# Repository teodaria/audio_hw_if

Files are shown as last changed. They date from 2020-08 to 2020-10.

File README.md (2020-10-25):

# hw_dev

This board is designed around AD1983 codec as an expansion board for the STM32MP157C-DK2 evaluation board.
It adds the capability to connect musical intruments to the STM32MP1 and output the processed audio with low latency.

Main features:
 * [AD1983](https://www.analog.com/en/products/ad1983.html) 4 in / 8 out codec
 * [LDLN030](https://www.st.com/en/power-management/ldln030.html) ultra-low noise LDO to generate a clean analog power for the codec and the analog circuitry
 * [TS922](https://www.st.com/content/st_com/en/products/amplifiers-and-comparators/operational-amplifiers-op-amps/automotive-op-amps/ts922.html) low noise audio operational amplifiers
 * 2 input connectors
 * 2 output connectors
 * headphones connector

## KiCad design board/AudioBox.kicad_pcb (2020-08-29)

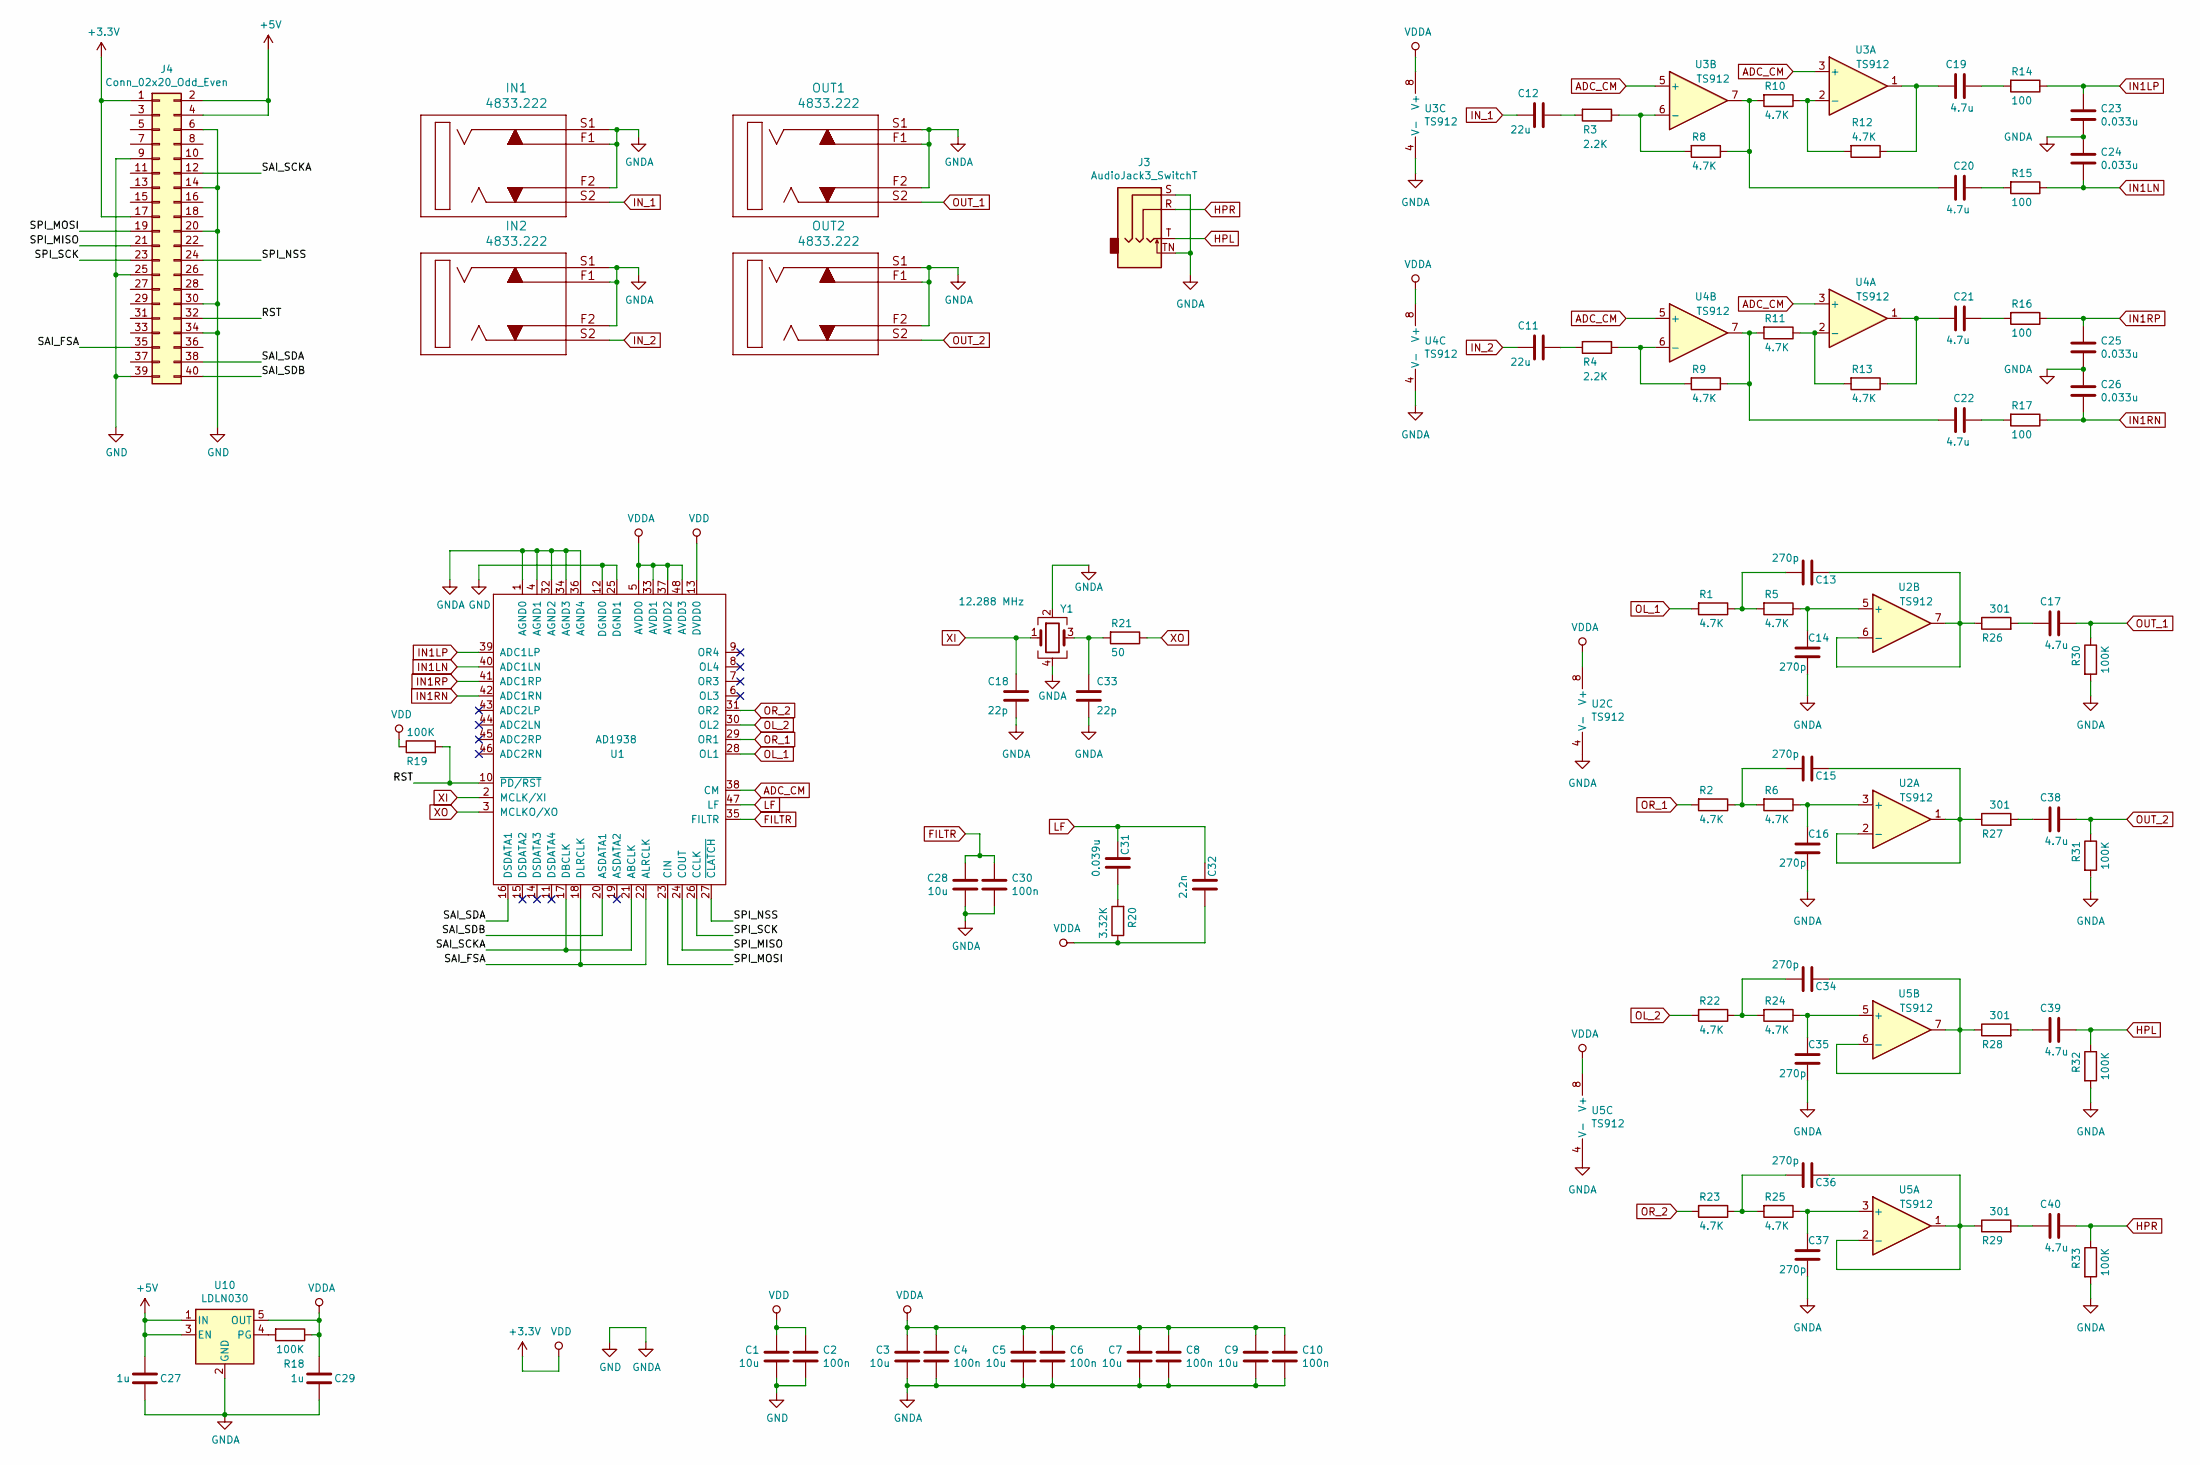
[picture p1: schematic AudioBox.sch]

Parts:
C1, C3, C5, C7, C9, C28: 10u; C_0603_1608Metric_Pad1.05x0.95mm_HandSolder; Voltage 25V; Tolerance 10%
C2, C4, C6, C8, C10, C30: 100n; C_0603_1608Metric_Pad1.05x0.95mm_HandSolder; Voltage 25V; Tolerance 10%
C11, C12: 22u; C_0603_1608Metric_Pad1.05x0.95mm_HandSolder; Voltage 10V; Tolerance 20%
C13, C14, C15, C16, C34, C35, C36, C37: 270p; C_0603_1608Metric_Pad1.05x0.95mm_HandSolder; Voltage 100V; Tolerance 1%
C17, C19, C20, C21, C22, C38, C39, C40: 4.7u; C_0603_1608Metric_Pad1.05x0.95mm_HandSolder; Voltage 16V; Tolerance 10%
C18, C33: 22p; C_0603_1608Metric_Pad1.05x0.95mm_HandSolder; Voltage 16V; Tolerance 5%
C23, C24, C25, C26: 0.033u; C_0603_1608Metric_Pad1.05x0.95mm_HandSolder; Voltage 16V; Tolerance 10%
C27, C29: 1u; C_0603_1608Metric_Pad1.05x0.95mm_HandSolder; Voltage 16V; Tolerance 10%
C31: 0.039u; C_0603_1608Metric_Pad1.05x0.95mm_HandSolder; Voltage 50V; Tolerance 10%
C32: 2.2n; C_0603_1608Metric_Pad1.05x0.95mm_HandSolder; Voltage 50V; Tolerance 10%
IN1, IN2: 4833.222
J3: AudioJack3_SwitchT; Jack_3.5mm_CUI_SJ-3524-SMT_Horizontal
J4: Conn_02x20_Odd_Even; PinSocket_2x20_P2.54mm_Vertical
OUT1, OUT2: 4833.222
R1, R2, R5, R6, R8, R9, R10, R11, R12, R13, R22, R23, R24, R25: 4.7K; R_0603_1608Metric_Pad1.05x0.95mm_HandSolder; Tolerance 1%
R3, R4: 2.2K; R_0603_1608Metric_Pad1.05x0.95mm_HandSolder; Tolerance 1%
R14, R15, R16, R17: 100; R_0603_1608Metric_Pad1.05x0.95mm_HandSolder; Tolerance 1%
R18, R19, R30, R31, R32, R33: 100K; R_0603_1608Metric_Pad1.05x0.95mm_HandSolder; Tolerance 5%
R20: 3.32K; R_0603_1608Metric_Pad1.05x0.95mm_HandSolder; Tolerance 1%
R21: 50; R_0603_1608Metric_Pad1.05x0.95mm_HandSolder; Tolerance 1%
R26, R27, R28, R29: 301; R_0603_1608Metric_Pad1.05x0.95mm_HandSolder; Tolerance 1%
U1: AD1938; LQFP-48_7x7mm_P0.5mm
U2, U3, U4, U5: TS912; SO-8_5.3x6.2mm_P1.27mm
U10: LDLN030; SOT-23-5
Y1: 12.288 MHz; Crystal_SMD_Abracon_ABM3B-4Pin_5.0x3.2mm

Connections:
+3V3: C1.2, C2.2, J4.1, J4.17, R19.1, U1.13 (DVDD0)
+5V: C27.2, J4.2, J4.4, U10.1 (IN), U10.3 (EN)
/RST: J4.32, R19.2, U1.10 (~PD/RST)
/SAI_FSA: J4.35, U1.18 (DLRCLK), U1.22 (ALRCLK)
/SAI_SCKA: J4.12, U1.17 (DBCLK), U1.21 (ABCLK)
/SAI_SDA: J4.38, U1.16 (DSDATA1)
/SAI_SDB: J4.40, U1.20 (ASDATA1)
/SPI_MISO: J4.21, U1.24 (COUT)
/SPI_MOSI: J4.19, U1.23 (CIN)
/SPI_NSS: J4.24, U1.27 (~CLATCH)
/SPI_SCK: J4.23, U1.26 (CCLK)
ADC_CM: U1.38 (CM), U3.3 (+), U3.5 (+), U4.3 (+), U4.5 (+)
FILTR: C28.2, C30.2, U1.35 (FILTR)
GND: C1.1, C2.1, C3.1, C4.1, C5.1, C6.1, C7.1, C8.1, C9.1, C10.1, C14.2, C16.2, C18.1, C23.1, C24.2, C25.1, C26.2, C27.1, C28.1, C29.1, C30.1, C33.1, C35.2, C37.2, IN1.F1, IN1.F2, IN1.S1, IN2.F1, IN2.F2, IN2.S1, J3.S, J3.TN, J4.6, J4.9, J4.14, J4.20, J4.25, J4.30, J4.34, J4.39, OUT1.F1, OUT1.F2, OUT1.S1, OUT2.F1, OUT2.F2, OUT2.S1, R30.2, R31.2, R32.2, R33.2, U1.1 (AGND0), U1.4 (AGND1), U1.12 (DGND0), U1.25 (DGND1), U1.32 (AGND2), U1.34 (AGND3), U1.36 (AGND4), U2.4 (V-), U3.4 (V-), U4.4 (V-), U5.4 (V-), U10.2 (GND), Y1.2, Y1.4
HPL: C39.1, J3.T, R32.1
HPR: C40.1, J3.R, R33.1
IN1LN: C24.1, R15.1, U1.40 (ADC1LN)
IN1LP: C23.2, R14.1, U1.39 (ADC1LP)
IN1RN: C26.1, R17.1, U1.42 (ADC1RN)
IN1RP: C25.2, R16.1, U1.41 (ADC1RP)
IN_1: C12.2, IN1.S2
IN_2: C11.2, IN2.S2
LF: C31.1, C32.1, U1.47 (LF)
unnamed: C11.1, R4.2
unnamed: C12.1, R3.2
unnamed: C13.1, R26.1, U2.6 (-), U2.7
unnamed: C13.2, R1.1, R5.2
unnamed: C14.1, R5.1, U2.5 (+)
unnamed: C15.1, R27.1, U2.1, U2.2 (-)
unnamed: C15.2, R2.1, R6.2
unnamed: C16.1, R6.1, U2.3 (+)
unnamed: C17.2, R26.2
unnamed: C19.1, R14.2
unnamed: C19.2, R12.1, U3.1
unnamed: C20.1, R8.1, R10.2, U3.7
unnamed: C20.2, R15.2
unnamed: C21.1, R13.1, U4.1
unnamed: C21.2, R16.2
unnamed: C22.1, R9.1, R11.2, U4.7
unnamed: C22.2, R17.2
unnamed: C31.2, R20.2
unnamed: C33.2, R21.2, Y1.3
unnamed: C34.1, R28.1, U5.6 (-), U5.7
unnamed: C34.2, R22.1, R24.2
unnamed: C35.1, R24.1, U5.5 (+)
unnamed: C36.1, R29.1, U5.1, U5.2 (-)
unnamed: C36.2, R23.1, R25.2
unnamed: C37.1, R25.1, U5.3 (+)
unnamed: C38.2, R27.2
unnamed: C39.2, R28.2
unnamed: C40.2, R29.2
unnamed: R3.1, R8.2, U3.6 (-)
unnamed: R4.1, R9.2, U4.6 (-)
unnamed: R10.1, R12.2, U3.2 (-)
unnamed: R11.1, R13.2, U4.2 (-)
unnamed: R18.2, U10.4 (PG)
OL_1: R1.2, U1.28 (OL1)
OL_2: R22.2, U1.30 (OL2)
OR_1: R2.2, U1.29 (OR1)
OR_2: R23.2, U1.31 (OR2)
OUT_1: C17.1, OUT1.S2, R30.1
OUT_2: C38.1, OUT2.S2, R31.1
VDDA: C3.2, C4.2, C5.2, C6.2, C7.2, C8.2, C9.2, C10.2, C29.2, C32.2, R18.1, R20.1, U1.5 (AVDD0), U1.33 (AVDD1), U1.37 (AVDD2), U1.48 (AVDD3), U2.8 (V+), U3.8 (V+), U4.8 (V+), U5.8 (V+), U10.5 (OUT)
XI: C18.2, U1.2 (MCLK/XI), Y1.1
XO: R21.1, U1.3 (MCLKO/XO)

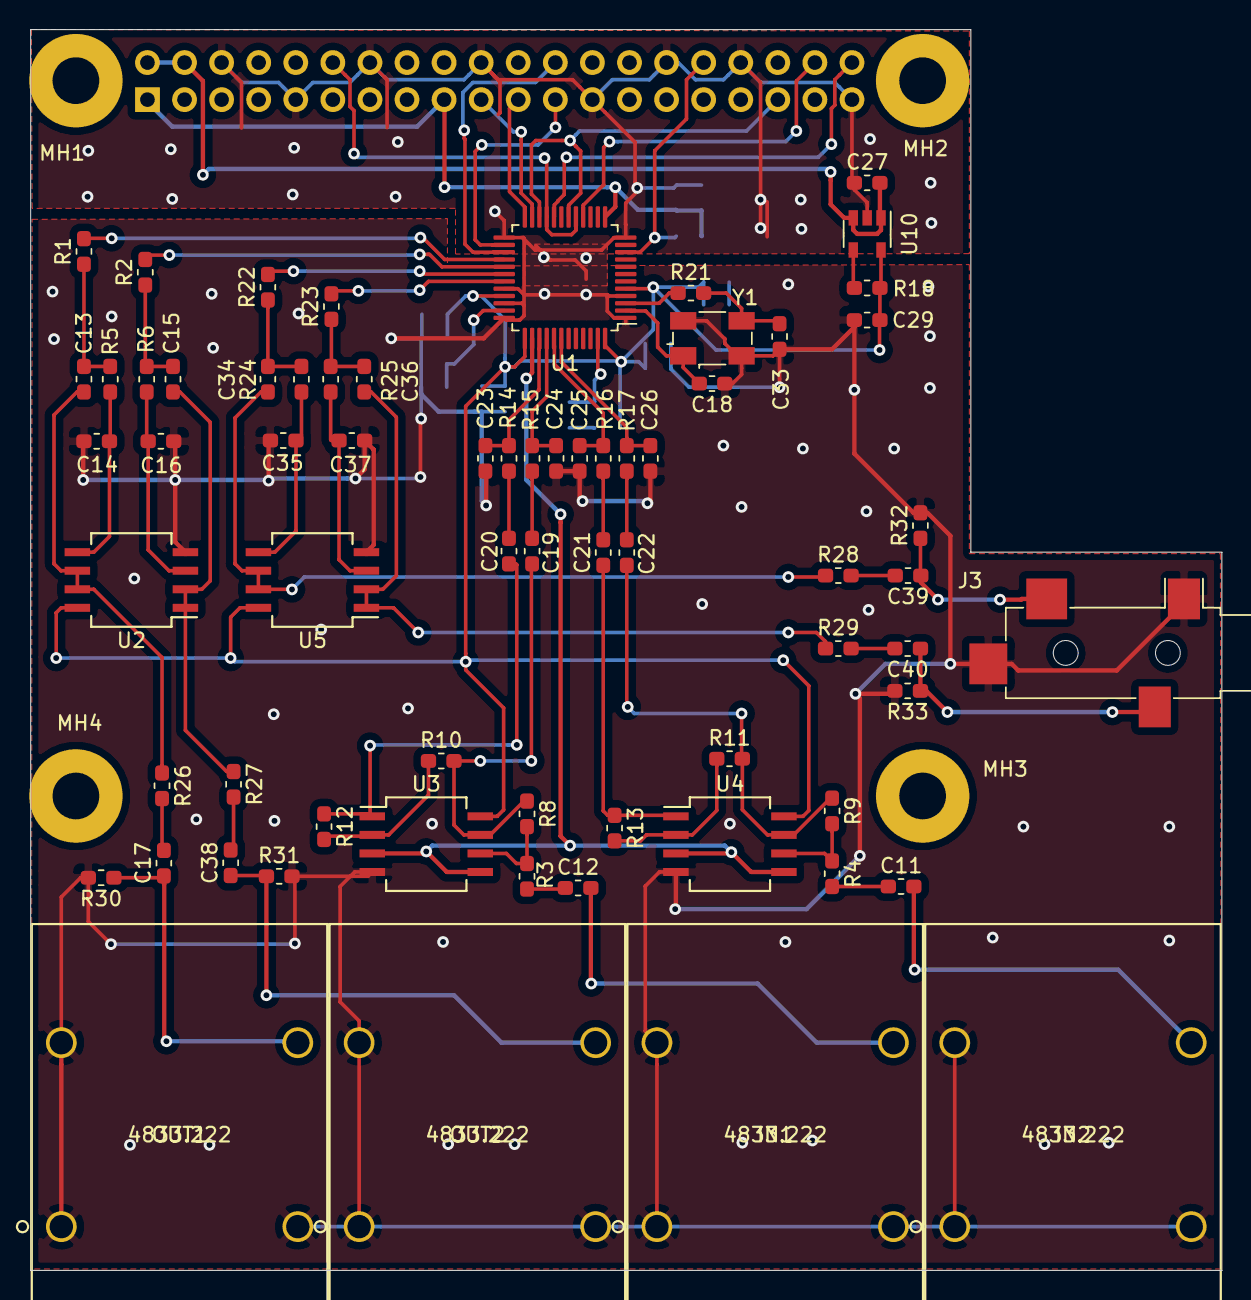
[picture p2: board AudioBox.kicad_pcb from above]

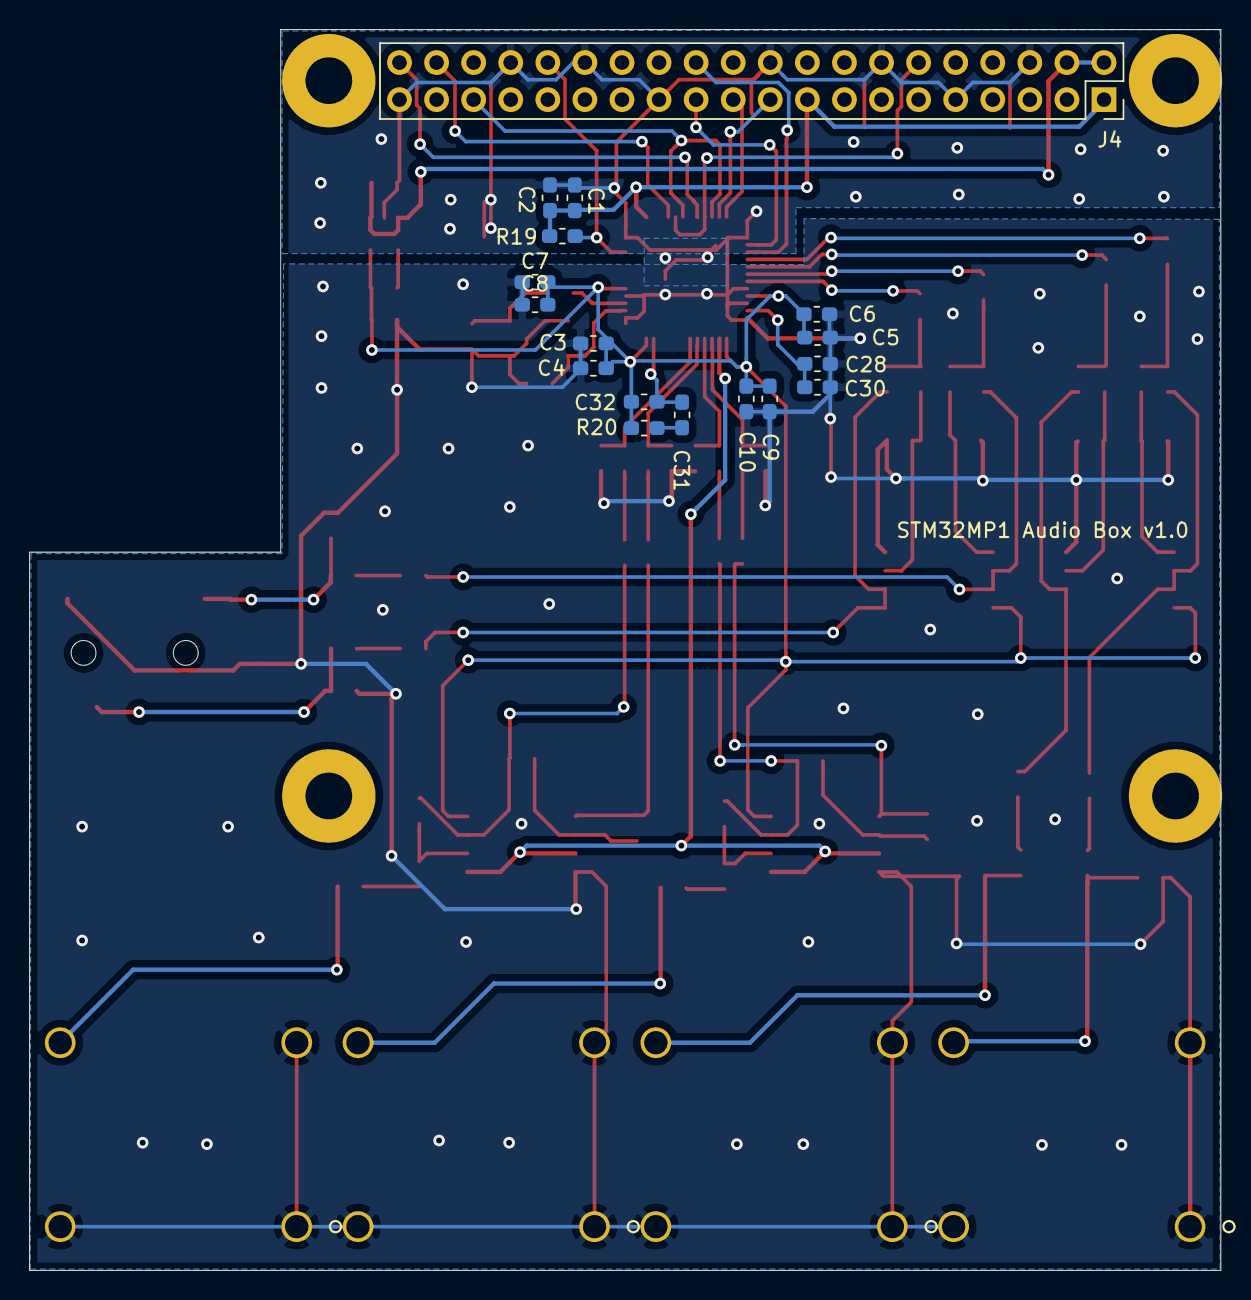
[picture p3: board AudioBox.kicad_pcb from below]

Board: 2 copper layers, 81.6 x 85.0 mm, 89 parts (17 on the bottom side), 65 nets.

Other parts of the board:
MH1, MH2, MH3, MH4: MountingHole_3.2mm_M3_Pad

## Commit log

2020-08-20 First dev version
    [AudioBox.kicad_pcb, AudioBox.sch]
2020-08-27 half placement done
    [AudioBox.kicad_pcb, AudioBox.sch]
2020-08-28 finished routing. Silkskreen to do
    [AudioBox.kicad_pcb]
2020-08-29 updated silkscreen
    [AudioBox.kicad_pcb]
2020-08-29 minor and generate Gerber
    [AudioBox-B_Cu.gbr, AudioBox-B_Mask.gbr, AudioBox-B_Paste.gbr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]
2020-10-24 modified resistor values of the input buffer
    [AudioBox.sch]

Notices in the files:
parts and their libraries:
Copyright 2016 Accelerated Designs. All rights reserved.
